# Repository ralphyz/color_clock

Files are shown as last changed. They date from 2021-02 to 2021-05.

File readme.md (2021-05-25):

# Color Clock
This traffic-light clock was designed to help my daughter understand when she can get out of bed in the morning.  

* Red - go back to bed
* Yellow - almost time, play in your bed if you wish
* Green - you can get up now

It has a simple design and a customizable schedule that can be programmed from the web interface.  This clock uses Python3 to control the GPIO Pins on the Raspberry Pi Zero and also run the simple web server.  This guide will give you all the software, inluding the OpenSCAD 3D model for the case, to allow you to create one of your own.  Just supply the hardware, print the case, and load the software.

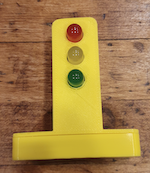
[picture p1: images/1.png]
Color Clock


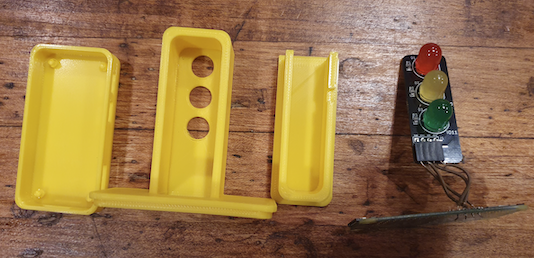
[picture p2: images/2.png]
Color Clock Parts


## Hardware Needed
* Rasberry Pi Zero W V1.1 [https://amzn.to/2YNBUNQ](https://amzn.to/2YNBUNQ)
* Low Voltage Labs Traffic Light [https://amzn.to/2MVWmtl](https://amzn.to/2MVWmtl)
* Micro SDCard [https://amzn.to/3rnInvc](https://amzn.to/3rnInvc)

## Skills needed
* Familiarity with Raspberry Pi
* SSH into a computer
* Basic soldering
* Basic command line experience 
* 3D printing

## Soldering
You may be able to get by without soldering, but I soldered the wires onto my board.  I did not solder into the traffic light device. I used GPIO spots GND/17/27/22 and wires that are 40mm long. You can use 14/15/18/GND too, and you will not have to rotate the light 180 degrees. If you change GPIO pins, you must update the `monitor.py` file with the new locations:
```
# GPIO Pin Numbers
g_io = 17
r_io = 27
y_io = 22
```
## Case and Assembly
Once soldered, put the traffic lights onto the wires.  With the lights facing towards the USB/HDMI ports, insert the wires, in sequence left to right, into the traffic light.  While slightly pushing down, twist the traffic light 180 degrees, facing away from the ports.  Next, place the PI Zero into the base of the case.  Fit the traffic light through the hole in the top/lid part of the case, and then snap the top/lid down onto the base.  Then, gently press the LEDs into the holes on the front.  Once it is securely in place, fit the back of the light tower into place to secure the traffic light in the tower.

## Getting the Pi ready for booting
1. Download the latest image for your pi at [www.raspberrypi.org](https://www.raspberrypi.org/software/operating-systems/)

1. Use software, such as [Etcher](https://www.balena.io/etcher/), to burn the image onto the SDCard

1. Re-insert the SDCard into your computer (where you burned the image) and browse to the /boot directory on the card

1. Create an empty file called `ssh`
1. Create a file called `wpa_supplicant.conf`. It should look like this:
```
country=US
update_config=1
ctrl_interface=/var/run/wpa_supplicant

network={
 scan_ssid=1
 ssid="YOUR_NETWORK_SSID"
 psk="your_password"
}
```
Be sure to use your SSID (Wifi network name) and password for your network. 

## Boot the Pi
Now put the SDCard into the pi and turn it on. When it comes online, it will have SSH enabled.  If it does not connect, be sure you have the SSID (wireless name) and PSK (wireless password) correct.  Without HDMI and keyboard, you will have to find the device on your network. You need the IP address to log in and set it up.

SSH into the machine, using `raspberry` as the default password
```
#ssh pi@ip_address
#example:
ssh pi@192.168.1.100
```
Make sure to fully update your pi
```
sudo apt update
sudo apt -y upgrade
```
Install Pip and Git
```
sudo apt -y install python3-pip git
```
Clone this repo
```
https://github.com/ralphyz/color_clock.git
```
Install the required Python modules
```
cd color_clock
pip -r install requirements.txt
```

Schedule the program to run when the unit is rebooted:
```
crontab -l > mycron && echo "@reboot /usr/bin/python3 /home/pi/color_clock/monitor.py 2>/dev/null" >> mycron && crontab mycron && rm mycron
crontab -l > mycron && echo "@reboot /usr/bin/python3 /home/pi/color_clock/app.py 2>/dev/null" >> mycron && crontab mycron && rm mycron
```
Reboot to start the color clock!
```
sudo reboot
```

## Web Server
Once the pi reboots, you should be able to browse to the web server in any browser by typing in the IP Address.  From the page that loads, you can touch a LED to enable that color.  When a color is enabled and it is not the scheduled time for that color, the "Temporary Override" button will turn on.  You can click it off, or you can select a different LED.  

You may also select the Schedule Tab, and set the schedule for the light changes.

## Conclusion
I hope this small project helps someone else.  It was fun to write, and fun to see my daughter use. Also, please change your pi's password.

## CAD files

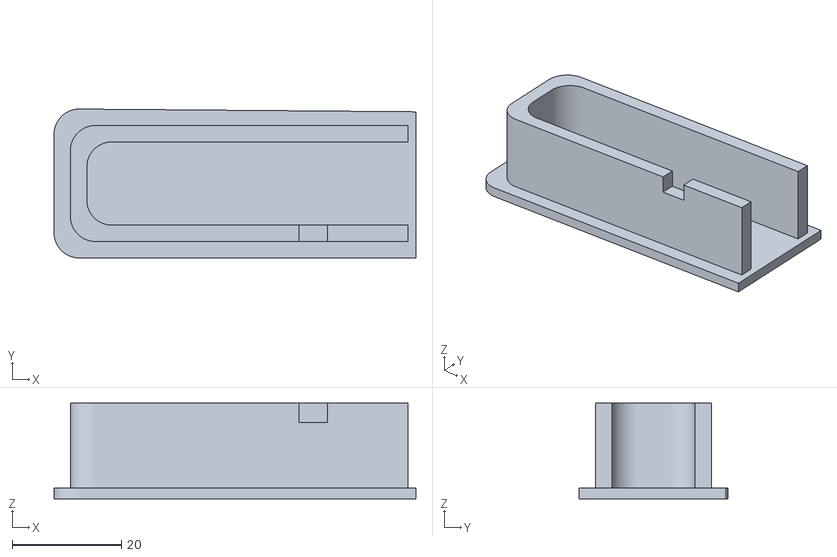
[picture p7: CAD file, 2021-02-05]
3D/pi_zero_led_clock_back.stl
66.2 x 27.2 x 17.5

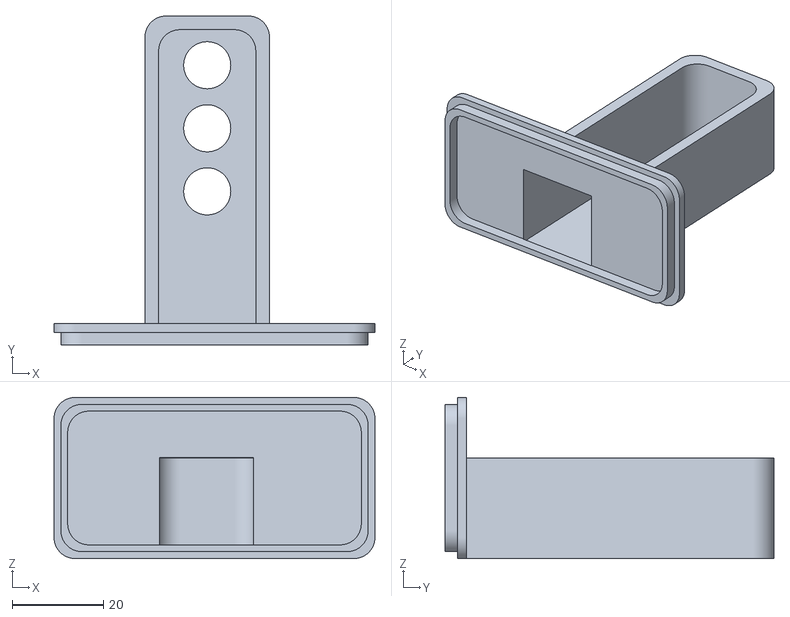
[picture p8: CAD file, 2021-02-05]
3D/pi_zero_led_clock_lid.stl
70.3 x 72.0 x 35.2

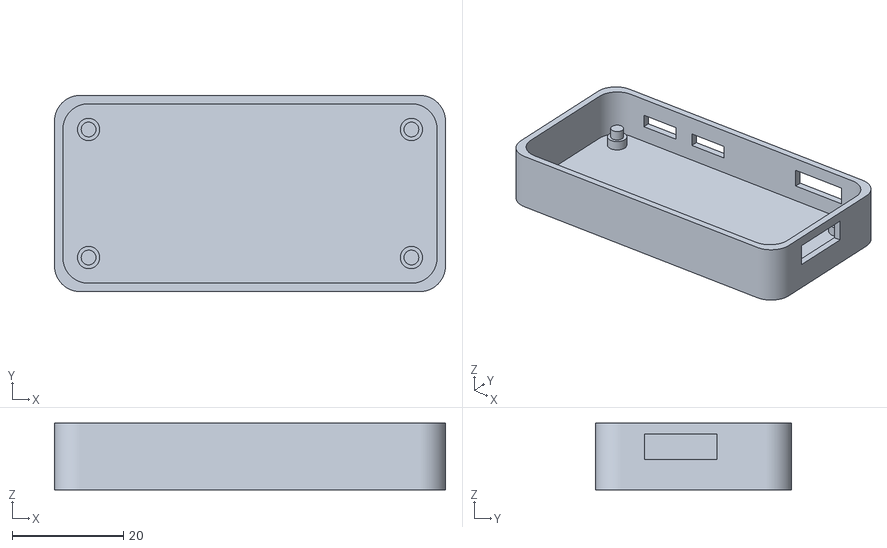
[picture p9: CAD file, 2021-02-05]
3D/pi_zero_led_clock_base.stl
70.2 x 35.2 x 12.0

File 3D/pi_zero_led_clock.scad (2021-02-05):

//dimensions measured with calipers and confirmed here:
//https://www.electronics-lab.com/raspberry-pi-zero-footprint-and-dimensions/
//This does not have the camera port

pi_z_1_3_w = 30;
pi_z_1_3_l = 65;
pi_z_1_3_spacing_w = 23;
pi_z_1_3_spacing_l = 58;

outter_spacing = 3;
pi_z_1_3_outter_spacing_w = pi_z_1_3_spacing_w + outter_spacing;
pi_z_1_3_outter_spacing_l = pi_z_1_3_spacing_l + outter_spacing;
pi_z_1_3_inner_spacing_w = pi_z_1_3_spacing_w - outter_spacing;
pi_z_1_3_inner_spacing_l = pi_z_1_3_spacing_l - outter_spacing;

pi_z_1_3_hole_d = 2.65;
pi_z_1_3_spacer_d = 4;
pi_z_1_3_hole_padding = 3.5;
pi_z_1_3_corner_d = 9.25;

micro_usb_w = 8.45;
micro_usb_h = 4.25;

mini_hdmi_w = 12;
mini_hdmi_h = 5.25;

micro_sdcard_w = 13;
micro_sdcard_h = 6;

pi_z_1_3_camera_w = 18.5;
pi_z_1_3_camera_h = 3;

pi_z_1_3_h = 1.5;

pi_z_1_3_hdmi_middle = 12.4;
pi_z_1_3_usb1_middle = 41.4;
pi_z_1_3_usb2_middle = 54;
pi_z_1_3_sdcard_middle = 16.9;

fn = 128;

thickness = 2;
lid_thickness = 2.75;
outter_height = 12;
padding = 0.75;

led_diam = 10.3; //9.8;
led_d = 19; //9.5;
led_w = 18; //22;
led_l = 53;
edge_space = 3;
led_space = 3.5;

module make_base()
{
    difference()
    {
        translate([-outter_spacing/2, -outter_spacing/2, 0])
        hull()
        {
            cylinder(d = pi_z_1_3_corner_d, h = outter_height, $fn = fn);
            translate([pi_z_1_3_outter_spacing_l, 0, 0])cylinder(d = pi_z_1_3_corner_d, h = outter_height, $fn = fn);
            translate([pi_z_1_3_outter_spacing_l, pi_z_1_3_outter_spacing_w, 0])cylinder(d = pi_z_1_3_corner_d, h = outter_height, $fn = fn);
            translate([0, pi_z_1_3_outter_spacing_w, 0])cylinder(d = pi_z_1_3_corner_d, h = outter_height, $fn = fn);
        }

        hull()
        {
            cylinder(d = pi_z_1_3_corner_d, h = outter_height+1, $fn = fn);
            translate([pi_z_1_3_spacing_l, 0, 0])cylinder(d = pi_z_1_3_corner_d, h = outter_height+1, $fn = fn);
            translate([pi_z_1_3_spacing_l, pi_z_1_3_spacing_w, 0])cylinder(d = pi_z_1_3_corner_d, h = outter_height+1, $fn = fn);
            translate([0, pi_z_1_3_spacing_w, 0])cylinder(d = pi_z_1_3_corner_d, h = outter_height+1, $fn = fn);
        }

        //camera
        //color("red")translate([-thickness*3,pi_z_1_3_spacing_w/2 - pi_z_1_3_camera_w/2-padding,thickness*2+pi_z_1_3_h])cube([thickness * 3,  pi_z_1_3_camera_w, pi_z_1_3_camera_h - pi_z_1_3_h]);

        //micro sdcard
        color("red")translate([-thickness*3 + pi_z_1_3_l,-micro_sdcard_w/2 + pi_z_1_3_sdcard_middle/2 + padding,thickness*2+pi_z_1_3_h])cube([thickness * 3,  micro_sdcard_w, micro_sdcard_h - pi_z_1_3_h]);


        //mini hdmi
        color("red")translate([-mini_hdmi_w/2+pi_z_1_3_l-pi_z_1_3_hole_d-pi_z_1_3_hdmi_middle - padding,pi_z_1_3_w-mini_hdmi_w/2,thickness*2+pi_z_1_3_h])cube([mini_hdmi_w, thickness * 3,  mini_hdmi_h - pi_z_1_3_h]);

        //micro usb1
        color("red")translate([-micro_usb_w/2+pi_z_1_3_l-pi_z_1_3_hole_d-pi_z_1_3_usb1_middle - padding,pi_z_1_3_w-micro_usb_w/2,thickness*2+pi_z_1_3_h])cube([micro_usb_w, thickness * 3,  micro_usb_h - pi_z_1_3_h]);

        //micro usb2
        color("red")translate([-micro_usb_w/2+pi_z_1_3_l-pi_z_1_3_hole_d-pi_z_1_3_usb2_middle - padding,pi_z_1_3_w-micro_usb_w/2,thickness*2+pi_z_1_3_h])cube([micro_usb_w, thickness * 3,  micro_usb_h - pi_z_1_3_h]);

    }


    //the mounting base
    color("green")
    {

        hull()
        {
            cylinder(d = pi_z_1_3_corner_d, h = thickness, $fn = fn);
            translate([pi_z_1_3_spacing_l, 0, 0])cylinder(d = pi_z_1_3_corner_d, h = thickness, $fn = fn);
            translate([pi_z_1_3_spacing_l, pi_z_1_3_spacing_w, 0])cylinder(d = pi_z_1_3_corner_d, h = thickness, $fn = fn);
            translate([0, pi_z_1_3_spacing_w, 0])cylinder(d = pi_z_1_3_corner_d, h = thickness, $fn = fn);
        }

        cylinder(d = pi_z_1_3_hole_d, h = thickness * 3, $fn = fn);
        translate([pi_z_1_3_spacing_l, 0, 0])cylinder(d = pi_z_1_3_hole_d, h = thickness * 3, $fn = fn);
        translate([pi_z_1_3_spacing_l, pi_z_1_3_spacing_w, 0])cylinder(d = pi_z_1_3_hole_d, h = thickness * 3, $fn = fn);
        translate([0, pi_z_1_3_spacing_w, 0])cylinder(d = pi_z_1_3_hole_d, h = thickness * 3, $fn = fn);


        cylinder(d = pi_z_1_3_spacer_d, h = thickness * 2, $fn = fn);
        translate([pi_z_1_3_spacing_l, 0, 0])cylinder(d = pi_z_1_3_spacer_d, h = thickness * 2, $fn = fn);
        translate([pi_z_1_3_spacing_l, pi_z_1_3_spacing_w, 0])cylinder(d = pi_z_1_3_spacer_d, h = thickness * 2, $fn = fn);
        translate([0, pi_z_1_3_spacing_w, 0])cylinder(d = pi_z_1_3_spacer_d, h = thickness * 2, $fn = fn);
    }
}

module make_lid()
{
    //the mounting base
    color("green")
    {
       
        translate([-outter_spacing/2, -outter_spacing/2, 0])
        hull()
        {
            cylinder(d = pi_z_1_3_corner_d, h = thickness, $fn = fn);
            translate([pi_z_1_3_outter_spacing_l, 0, 0])cylinder(d = pi_z_1_3_corner_d, h = thickness, $fn = fn);
            translate([pi_z_1_3_outter_spacing_l, pi_z_1_3_outter_spacing_w, 0])cylinder(d = pi_z_1_3_corner_d, h = thickness, $fn = fn);
            translate([0, pi_z_1_3_outter_spacing_w, 0])cylinder(d = pi_z_1_3_corner_d, h = thickness, $fn = fn);
        }
       translate([0,0,thickness])
       difference()
        {
        hull()
        {
            cylinder(d = pi_z_1_3_corner_d, h = lid_thickness, $fn = fn);
            translate([pi_z_1_3_spacing_l, 0, 0])cylinder(d = pi_z_1_3_corner_d, h = lid_thickness, $fn = fn);
            translate([pi_z_1_3_spacing_l, pi_z_1_3_spacing_w, 0])cylinder(d = pi_z_1_3_corner_d, h = lid_thickness, $fn = fn);
            translate([0, pi_z_1_3_spacing_w, 0])cylinder(d = pi_z_1_3_corner_d, h = lid_thickness, $fn = fn);
        }
        
        translate([+outter_spacing/2, +outter_spacing/2, 0])
        hull()
        {
            cylinder(d = pi_z_1_3_corner_d, h = lid_thickness+1, $fn = fn);
            translate([pi_z_1_3_inner_spacing_l, 0, 0])cylinder(d = pi_z_1_3_corner_d, h = lid_thickness+1, $fn = fn);
            translate([pi_z_1_3_inner_spacing_l, pi_z_1_3_inner_spacing_w, 0])cylinder(d = pi_z_1_3_corner_d, h = lid_thickness+1, $fn = fn);
            translate([0, pi_z_1_3_inner_spacing_w, 0])cylinder(d = pi_z_1_3_corner_d, h = lid_thickness+1, $fn = fn);
        }
        }

    }
}

module make_led_holder()
{

   
    
    difference()
    {
        hull()
        {
            cylinder(d = pi_z_1_3_corner_d, h = thickness, $fn = fn);
            translate([-pi_z_1_3_corner_d/2+pi_z_1_3_spacing_l, -pi_z_1_3_corner_d/2,0])cube([pi_z_1_3_corner_d, pi_z_1_3_corner_d, thickness]);
            translate([0, led_w,0])cylinder(d = pi_z_1_3_corner_d, h = thickness, $fn = fn);
            translate([pi_z_1_3_spacing_l-pi_z_1_3_corner_d/2, led_w-pi_z_1_3_corner_d/2, 0])cube([pi_z_1_3_corner_d, pi_z_1_3_corner_d, thickness]);
        }
        
        //slightly taller than the base, so the holes are clear in preview mode
        for( j = [0 : 2] )
            translate([1 + led_diam/2 + led_diam * j + led_space * j, led_w/2, -0.5])cylinder(d=led_diam, h=thickness+1, $fn=fn);
    }
    
    for ( i = [1 : 10] )
    {
        translate([0,0,thickness*i])
        difference()
        {
            hull()
            {
                cylinder(d = pi_z_1_3_corner_d, h = thickness, $fn = fn);
                translate([-pi_z_1_3_corner_d/2+pi_z_1_3_spacing_l, -pi_z_1_3_corner_d/2,0])cube([pi_z_1_3_corner_d, pi_z_1_3_corner_d, thickness]);
                translate([0, led_w,0])cylinder(d = pi_z_1_3_corner_d, h = thickness, $fn = fn);
                translate([pi_z_1_3_spacing_l-pi_z_1_3_corner_d/2, led_w-pi_z_1_3_corner_d/2, 0])cube([pi_z_1_3_corner_d, pi_z_1_3_corner_d, thickness]);
            }
            
            hull()
            {
                translate([edge_space, edge_space, -0.5])cylinder(d = pi_z_1_3_corner_d, h = thickness+1, $fn = fn);
                translate([-pi_z_1_3_corner_d/2+pi_z_1_3_spacing_l+1, -pi_z_1_3_corner_d/2+edge_space,-0.5])cube([pi_z_1_3_corner_d, pi_z_1_3_corner_d, thickness+1]);
                translate([edge_space, led_w-edge_space,-0.5])cylinder(d = pi_z_1_3_corner_d, h = thickness+1, $fn = fn);
                translate([pi_z_1_3_spacing_l-pi_z_1_3_corner_d/2+1, led_w-pi_z_1_3_corner_d/2-edge_space, -0.5])cube([pi_z_1_3_corner_d, pi_z_1_3_corner_d, thickness+1]);
            }
        }
    }
    
   
}
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

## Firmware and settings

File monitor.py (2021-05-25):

import sys, json, time, datetime
from datetime import datetime
from datetime import timedelta
from apscheduler.schedulers.background import BackgroundScheduler
from watchdog.observers import Observer
from watchdog.events import PatternMatchingEventHandler
import RPi.GPIO as GPIO

# start
# read file
# schedule tasks
# monitor files
#    when files change, delete schedules, reschedule
# max_instances = 1

#The job for scheduling the light change
schedule_id = "color_clock_id"

#The scheduler
schedule = None
light_job = None

# Global variables
config_file = 'config.json'
web_file = 'web.json'
red_start = 'red_start'
green_start = 'green_start'
yellow_start = 'yellow_start'
yellow_mode = 'yellow_mode'
override = 'override'
override_time = 'override_start'
active = 'active'
next_led = 'next'
delimiter = ':'

# Colors
red = 'red'
green = 'green'
yellow = 'yellow'

def_yellow_start = '07:40'
def_green_start = '07:45'
def_red_start = '20:45'

# GPIO Numbers
g_io = 17
r_io = 27
y_io = 22

data = {}

#--------------------------------------------------------------------------------
#
#  name: Handler
#  desc: define the pattern for the web config file
#
#--------------------------------------------------------------------------------
class Handler(PatternMatchingEventHandler):
    def __init__(self):
        # Set the patterns for PatternMatchingEventHandler
        PatternMatchingEventHandler.__init__(self, patterns=[web_file], ignore_directories=True, case_sensitive=False)
    
    # Event is created, you can process it now
    #def on_created(self, event):
    #    schedule_light()

    # Config file is modified, read it
    def on_modified(self, event):
        read_web_config()


#--------------------------------------------------------------------------------
#
#  name: calculate_next_light
#  desc: determine which light should be active
#
#--------------------------------------------------------------------------------
def calculate_next_light(now=time.strftime('%H:%M')):
    global data

    new_time = datetime.now().strftime('%d:%m:%y:%H:%M')

    day, month, year, hour, minute = map(int, new_time.split(":"))

    add_day = False

    #if now < data[red_start] and now  < data[green_start] and now < data[yellow_start]:
        #today
    #    add_day = False
    if now > data[red_start] and now > data[green_start] and now > data[yellow_start]: # and data[override_time] != ''
        add_day = True

    if data[red_start] < data[yellow_start] < data[green_start]:
        if now < data[red_start] or now >= data[green_start]:
            if add_day:
                data[next_led] = red
                return datetime(year, month, day, int(data[red_start].split(":")[0]), int(data[red_start].split(":")[1])) + timedelta(days=1)
            else:
                data[next_led] = red
                return datetime(year, month, day, int(data[red_start].split(":")[0]), int(data[red_start].split(":")[1]))
        elif now >= data[red_start] and now < data[yellow_start]:
            data[next_led] = yellow
            return datetime(year, month, day, int(data[yellow_start].split(":")[0]), int(data[yellow_start].split(":")[1]))
        elif now >= data[yellow_start] and now < data[green_start]:
            data[next_led] = green
            return datetime(year, month, day, int(data[green_start].split(":")[0]), int(data[green_start].split(":")[1]))

    elif data[red_start] < data[green_start] < data[yellow_start]:
        if now < data[red_start] or now >= data[yellow_start]:
            if add_day:
                data[next_led] = red
                return datetime(year, month, day, int(data[red_start].split(":")[0]), int(data[red_start].split(":")[1])) + timedelta(days=1)
            else:
                data[next_led] = red
                return datetime(year, month, day, int(data[red_start].split(":")[0]), int(data[red_start].split(":")[1]))
        elif now >= data[red_start] and now < data[green_start]:
            data[next_led] = green
            return datetime(year, month, day, int(data[green_start].split(":")[0]), int(data[green_start].split(":")[1]))
        elif now >= data[green_start] and now < data[yellow_start]:
            data[next_led] = yellow
            return datetime(year, month, day, int(data[yellow_start].split(":")[0]), int(data[yellow_start].split(":")[1]))

    elif data[green_start] < data[yellow_start] < data[red_start]:
        if now < data[green_start] or now >= data[red_start]:
            if add_day:
                data[next_led] = green
                return datetime(year, month, day, int(data[green_start].split(":")[0]), int(data[green_start].split(":")[1])) + timedelta(days=1)
            else:
                data[next_led] = green
                return datetime(year, month, day, int(data[green_start].split(":")[0]), int(data[green_start].split(":")[1]))
        elif now >= data[green_start] and now < data[yellow_start]:
            data[next_led] = yellow
            return datetime(year, month, day, int(data[yellow_start].split(":")[0]), int(data[yellow_start].split(":")[1]))
        elif now >= data[yellow_start] and now < data[red_start]:
            data[next_led] = red
            return datetime(year, month, day, int(data[red_start].split(":")[0]), int(data[red_start].split(":")[1]))

    elif data[green_start] < data[red_start] < data[yellow_start]:
        if now < data[green_start] or now >= data[yellow_start]:
            if add_day:
                data[next_led] = green
                return datetime(year, month, day, int(data[green_start].split(":")[0]), int(data[green_start].split(":")[1])) + timedelta(days=1)
            else:
                data[next_led] = green
                return datetime(year, month, day, int(data[green_start].split(":")[0]), int(data[green_start].split(":")[1]))
        elif now >= data[green_start] and now < data[red_start]:
            data[next_led] = red
            return datetime(year, month, day, int(data[red_start].split(":")[0]), int(data[red_start].split(":")[1]))
        elif now >= data[red_start] and now < data[yellow_start]:
            data[next_led] = yellow
            return datetime(year, month, day, int(data[yellow_start].split(":")[0]), int(data[yellow_start].split(":")[1]))

    elif data[yellow_start] < data[red_start] < data[green_start]:
        if now < data[yellow_start] or now >= data[green_start]:
            if add_day:
                data[next_led] = yellow
                return datetime(year, month, day, int(data[yellow_start].split(":")[0]), int(data[yellow_start].split(":")[1])) + timedelta(days=1)
            else:
                data[next_led] = yellow
                return datetime(year, month, day, int(data[yellow_start].split(":")[0]), int(data[yellow_start].split(":")[1]))
        elif now >= data[yellow_start] and now < data[red_start]:
            data[next_led] = red
            return datetime(year, month, day, int(data[red_start].split(":")[0]), int(data[red_start].split(":")[1]))
        elif now >= data[red_start] and now < data[green_start]:
            data[next_led] = green
            return datetime(year, month, day, int(data[green_start].split(":")[0]), int(data[green_start].split(":")[1]))

    elif data[yellow_start] < data[green_start] < data[red_start]:
        if now < data[yellow_start] or now >= data[red_start]:
            if add_day:
                data[next_led] = yellow
                return datetime(year, month, day, int(data[yellow_start].split(":")[0]), int(data[yellow_start].split(":")[1])) + timedelta(days=1)
            else:
                data[next_led] = yellow
                return datetime(year, month, day, int(data[yellow_start].split(":")[0]), int(data[yellow_start].split(":")[1]))
        elif now >= data[yellow_start] and now < data[green_start]:
            data[next_led] = green
            return datetime(year, month, day, int(data[green_start].split(":")[0]), int(data[green_start].split(":")[1]))
        elif now >= data[green_start] and now < data[red_start]:
            data[next_led] = red
            return datetime(year, month, day, int(data[red_start].split(":")[0]), int(data[red_start].split(":")[1]))


    #shouldn't get here
    data[next_led] = red
    return datetime(year, month, day, int(data[red_start].split(":")[0]), int(data[red_start].split(":")[1]))


#--------------------------------------------------------------------------------
#
#  name: calculate_scheduled_light
#  desc: determine which light should be active
#
#--------------------------------------------------------------------------------
def calculate_scheduled_light(now=time.strftime('%H:%M')):
    global data
    
    if data[red_start] < data[yellow_start] < data[green_start]:
        if now < data[red_start] or now >= data[green_start]:
            return green
        elif now >= data[red_start] and now < data[yellow_start]:
            return red
        elif now >= data[yellow_start] and now < data[green_start]:
            return yellow

    elif data[red_start] < data[green_start] < data[yellow_start]:
        if now < data[red_start] or now >= data[yellow_start]:
            return yellow
        elif now >= data[red_start] and now < data[green_start]:
            return red
        elif now >= data[green_start] and now < data[yellow_start]:
            return green

    elif data[green_start] < data[yellow_start] < data[red_start]:
        print("got here")
        if now < data[green_start] or now >= data[red_start]:
            return red
        elif now >= data[green_start] and now < data[yellow_start]:
                return green
        elif now >= data[yellow_start] and now < data[red_start]:
                return yellow

    elif data[green_start] < data[red_start] < data[yellow_start]:
        if now < data[green_start] or now >= data[yellow_start]:
            return yellow
        elif now >= data[green_start] and now < data[red_start]:
            return green
        elif now >= data[red_start] and now < data[yellow_start]:
            return red

    elif data[yellow_start] < data[red_start] < data[green_start]:
        if now < data[yellow_start] or now >= data[green_start]:
            return green
        elif now >= data[yellow_start] and now < data[red_start]:
                return yellow
        elif now >= data[red_start] and now < data[green_start]:
            return red

    elif data[yellow_start] < data[green_start] < data[red_start]:
        if now < data[yellow_start] or now >= data[red_start]:
            return red
        elif now >= data[yellow_start] and now < data[green_start]:
            return yellow
        elif now >= data[green_start] and now < data[red_start]:
            return green

    return red


#--------------------------------------------------------------------------------
#
#  name: create_time_config
#  desc: get the default times for the lights. and write the config
#
#--------------------------------------------------------------------------------
def create_time_config():
    global data

    data = {
        red_start: def_red_start,
        green_start: def_green_start,
        yellow_start: def_yellow_start,        
        override: '',
        override_time: '',
        active: '',
        next_led: ''
    }

    with open(config_file, 'w') as outfile:
        json.dump(data, outfile)

#--------------------------------------------------------------------------------
#
#  name: write_time_config
#  desc: write the config file for the lights.
#
#--------------------------------------------------------------------------------
def write_time_config():
    global data

    with open(config_file, 'w') as f:
        json.dump(data, f)
    

#--------------------------------------------------------------------------------
#
#  name: read_light_config
#  desc: read the configuration file
#
#--------------------------------------------------------------------------------
def read_light_config():
    global data

    try:
        with open(config_file, 'r') as f:
            data = json.load(f)
    except:
        create_time_config()

    if data.get(red_start) is None:
        data[red_start] = def_red_start

    if data.get(green_start) is None:
        data[green_start] = def_green_start

    if data.get(yellow_start) is None:
        data[yellow_start] = def_yellow_start
        
    if data.get(override_time) is None:     
        data[override_time] = ''
        data[override] = ''
    elif data.get(override) is None:
        data[override_time] = ''
        data[override] = ''

    if data.get(yellow_mode) is None:
        data[yellow_mode] = True

#--------------------------------------------------------------------------------
#
#  name: read_web_config
#  desc: read the configuration file
#
#--------------------------------------------------------------------------------
def read_web_config():
    global data

    print("read web config")
    try:
        with open(web_file, 'r') as f:
            web_data = json.load(f)
    except:
        return

    web_red =  web_data.get(red_start, '')
    web_green =  web_data.get(green_start, '')
    web_yellow =  web_data.get(yellow_start, '')
    web_override =  web_data.get(override, '')
    web_override_time =  web_data.get(override_time, '')
    web_yellow_mode = web_data.get(yellow_mode, False)

    data[yellow_mode] = web_yellow_mode

    if web_override and web_override_time:
        h, m = web_override_time.split(delimiter)

        # make sure good values were sent
        if int(h) < 0 and int(h) > 24 and int(m) < 0 and int(m) > 59:
            return

        if web_override != red and web_override != green and web_override != yellow:
            return

        data[override] = web_override
        data[override_time] = web_override_time

        print("override")

    elif web_red and web_green and web_yellow:
        try:
            g_h, g_m = web_green.split(delimiter)
            y_h, y_m = web_yellow.split(delimiter)
            r_h, r_m = web_red.split(delimiter)

            # make sure good values were sent
            if int(g_h) < 0 and int(g_h) > 24 and int(g_m) < 0 and int(g_m) > 59 and int(r_h) < 0 and int(r_h) > 24 and int(r_m) < 0 and int(r_m) > 59:
                return

            # save the data
            data[red_start] = web_red
            data[green_start] = web_green
            data[yellow_start] = web_yellow
            data[override] = ''
            data[override_time] = ''

            print("schedule change")
        except:
            return

    activate_light()



    

#--------------------------------------------------------------------------------
#
#  name: activate_light
#  desc: enable the correct light
#
#--------------------------------------------------------------------------------
def activate_light():
    global light_job, schedule, data

    try:
        schedule.remove_job(schedule_id)
    except:
        pass

    led = ''

    scheduled = calculate_scheduled_light()
    print(scheduled)
    next_light_schedule = calculate_next_light()
    led = scheduled

    print(data[override])

    if data[override] == scheduled:
        data[override] = ''
        data[override_time] = ''

    if data[override_time] != '': 
        light_at_override = calculate_scheduled_light(data[override_time])

        if light_at_override != scheduled:
            data[override_time] = ''
            data[override] = ''
        else:
            led = data[override]

    if led == green:
        GPIO.output(g_io, True)
        GPIO.output(r_io, False)
        GPIO.output(y_io, False)

    elif led == red:
        GPIO.output(r_io, True)
        GPIO.output(g_io, False)
        GPIO.output(y_io, False)

    elif led == yellow:
        GPIO.output(y_io, True)
        GPIO.output(r_io, False)
        GPIO.output(g_io, False)
    
    #store the active and next LEDs - for the web server
    data[active] = led
    write_time_config()

    #Schedule the next event
    light_job = schedule.add_job(activate_light, trigger='date', next_run_time=next_light_schedule, id=schedule_id, max_instances=1, replace_existing=True)

    if schedule.state == 0:
        schedule.start()

    return led

#--------------------------------------------------------------------------------
#
#  name: __main__
#  desc: the default function when the script is run
#
#--------------------------------------------------------------------------------
if __name__ == '__main__':
    src_path = "."

    GPIO.setmode(GPIO.BCM)
    GPIO.setup(g_io, GPIO.OUT)
    GPIO.setup(r_io, GPIO.OUT)
    GPIO.setup(y_io, GPIO.OUT)


    # watch the config file for changes
    event_handler = Handler()
    observer = Observer()
    observer.schedule(event_handler, path=src_path, recursive=True)
    observer.start()

    schedule = BackgroundScheduler(daemon=True)
    schedule.start()

    read_light_config()
    activate_light()

    while True:
        time.sleep(1)

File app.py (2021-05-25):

from flask import Flask, render_template, request, redirect, url_for
import sys, json, time, datetime
from datetime import datetime

import RPi.GPIO as GPIO

app = Flask(__name__)

# Global variables
config_file = 'config.json'
web_file = 'web.json'
red_start = 'red_start'
green_start = 'green_start'
yellow_start = 'yellow_start'
next_led = 'next'
override = 'override'
override_time = 'override_start'
active = 'active'

mode = 'mode'
yellow_mode = 'yellow_mode'
green_notice = 'green_notice'

# Colors
red = 'red'
green = 'green'
yellow = 'yellow'
gray = 'gray'
led = 'led'
delimiter = ':'
index = "web_index"

def_green_start = '07:45'
def_red_start = '20:45'
def_yellow_start = '07:40'

data = {}

#--------------------------------------------------------------------------------
#
#  name: create_time_config
#  desc: get the default times for the lights. and write the config
#
#--------------------------------------------------------------------------------
def create_time_config():
    global data

    data = {
        red_start: def_red_start,
        green_start: def_green_start,
        yellow_start: def_yellow_start,
        next_led: '',
        override: '',
        override_time: '',
        active: ''
    }

    with open(config_file, 'w') as outfile:
        json.dump(data, outfile)

#--------------------------------------------------------------------------------
#
#  name: write_time_config
#  desc: write the config file for the lights.
#
#--------------------------------------------------------------------------------
def write_time_config():
    global data

    with open(web_file, 'w') as f:
        json.dump(data, f)

#--------------------------------------------------------------------------------
#
#  name: read_light_config
#  desc: read the configuration file
#
#--------------------------------------------------------------------------------
def read_light_config():
    global data

    try:
        with open(config_file, 'r') as f:
            data = json.load(f)
    except:
        create_time_config()

    if data.get(red_start) is None:
        data[red_start] = def_red_start

    if data.get(green_start) is None:
        data[green_start] = def_green_start

    if data.get(override_time) is None:
        data[override_time] = ''
        data[override] = ''
    elif data.get(override) is None:
        data[override_time] = ''
        data[override] = ''

    if data.get(yellow_mode) is None:
        data[yellow_mode] = False
    print(data[yellow_mode])

    if data.get(active) is None:
        data[active] = green

    try:
        g_h, g_m = data[green_start].split(delimiter)
        y_h, y_m = data[yellow_start].split(delimiter)
        r_h, r_m = data[red_start].split(delimiter)
    except:
        create_time_config

    # make sure good values were sent
    if int(g_h) < 0 and int(g_h) > 24 and int(g_m) < 0 and int(g_m) > 59 and int(r_h) < 0 and int(r_h) > 24 and int(r_m) < 0 and int(r_m) > 59:
        create_time_config

 
#--------------------------------------------------------------------------------
#
#  name: web_index
#  desc: the default page when / is called in the URL
#
#--------------------------------------------------------------------------------
@app.route('/')
def web_index():
    global data
    read_light_config()

    light = data[active]

    if data[override]:
        light = data[override]

    lights = {
        red:red if light == red else gray,
        green: green if light == green else gray,
        yellow: yellow if light == yellow else gray,
        override:True if data[override] else False
    }

    y_h, y_m = data[yellow_start].split(":")
    g_h, g_m = data[green_start].split(":")

    if int(g_m) > int(y_m):
        y_m = int(g_m) - int(y_m)
    else:
        y_m = (int(g_m) - int(y_m)) * -1
        
    times = {
        red:data[red_start],
        green:data[green_start],
        green_notice:y_m,
        yellow: data[yellow_start],
        mode: int(data[yellow_mode])
    }

    return render_template('main.html', title=light, light=lights, time=times, clock=time.strftime("%H:%M:%S"))

#--------------------------------------------------------------------------------
#
#  name: change_web_led
#  desc: a LED light was selected by the user
#
#--------------------------------------------------------------------------------
@app.route("/led", methods=["GET"])
def change_web_led():
    global data

    # make sure we have the latest
    read_light_config()

    new_led = request.args.get(led)
    print(new_led)
    data[override] = new_led
    data[override_time] = datetime.now().strftime('%H:%M')
    
    # writing the config will trigger the watchdog to update the LED
    write_time_config()
    time.sleep(0.2)
    return redirect(url_for(index))

#--------------------------------------------------------------------------------
#
#  name: normal
#  desc: remove override
#
#--------------------------------------------------------------------------------
@app.route("/normal", methods=["GET", "POST"])
def normal():
    global data

    data[override] = ""

    # writing the config will trigger the watchdog to update the LED
    write_time_config()

    return redirect(url_for(index))
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

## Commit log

2021-02-05 added 3D models
    [pi_zero_led_clock.scad, pi_zero_led_clock_back.stl, pi_zero_led_clock_base.stl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]
2021-02-07 adjustable min timer
